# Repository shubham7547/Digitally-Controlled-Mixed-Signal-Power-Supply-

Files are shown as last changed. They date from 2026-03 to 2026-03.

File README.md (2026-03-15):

# Digitally Controlled Mixed-Signal Power Supply


[]()
[]()

[]()

A high-performance, digitally controlled benchtop power supply that bridges digital precision with an ultra-fast analog regulation loop. The system delivers an adjustable **0 to 30.0 V** output at up to **1.0 A**, featuring dual rotary quadrature encoders with digit-level selection, high-resolution readbacks on a 2.8" color TFT display, and a non-blocking embedded firmware architecture.

Developed at the **Centre for Electronic Design and Technology (CEDT)**, **Netaji Subhas University of Technology (NSUT), New Delhi**.

---

## Table of Contents

- [Architectural Philosophy](#architectural-philosophy)
- [System Architecture](#system-architecture)
- [Key Specifications](#key-specifications)
- [Hardware & Circuit Design](#hardware--circuit-design)
  - [1. AC Input & Bulk Rectification](#1-ac-input--bulk-rectification)
  - [2. Dual Auxiliary Buck Regulators](#2-dual-auxiliary-buck-regulators)
  - [3. Digital Setpoint Generation](#3-digital-setpoint-generation)
  - [4. Analog Voltage Regulation Loop](#4-analog-voltage-regulation-loop)
  - [5. Current Sensing & Differential Amplification](#5-current-sensing--differential-amplification)
- [Pin Assignment Table](#pin-assignment-table)
- [Firmware Architecture](#firmware-architecture)
  - [Interrupt-Driven Quadrature Decoding](#interrupt-driven-quadrature-decoding)
  - [Non-Blocking Scheduling](#non-blocking-scheduling)
  - [Software Current Limit Foldback](#software-current-limit-foldback)
- [Repository Structure](#repository-structure)
- [Getting Started](#getting-started)
  - [Required Libraries](#required-libraries)
  - [Hardware Setup & Flashing](#hardware-setup--flashing)
- [Author & Affiliation](#author--affiliation)
- [License](#license)

---

## Architectural Philosophy

Simpler DIY microcontroller-based power supplies often place the digital microcontroller inside the primary feedback loop or use PWM/software loops to regulate output voltage, leading to slow transient response, ADC latency, and stability issues.

This design enforces a strict separation of concerns:
1. **Digital Setpoint Domain:** The **Arduino Nano** and **TLC5618A 12-bit DAC** determine what target voltage/current limit is desired. They never carry load current and never sit directly inside the fast closed loop.
2. **Analog Control Domain:** An **LM358 op-amp error amplifier** continuously compares the scaled output feedback against the DAC setpoint in real time, driving high-power series-pass transistors (**MJE2955T PNP**) instantaneously without digital latency.

---

## System Architecture

```mermaid
flowchart TD
    Mains["Mains 230V AC"] --> T1["Step-Down Transformer\n(Off-Board)"]
    T1 --> Bridge["Bridge Rectifier (1N4007)\n+ 2x 4700µF Series Caps (50V eff.)"]
    Bridge --> RawDC["Raw DC Bus (~36V Peak)"]

    RawDC --> VR6["LM2575 Buck 1\nStep-down to 5.29V"]
    VR6 --> MCU["Arduino Nano\n(5V Digital Rail)"]

    RawDC --> VR5["LM2575 Buck 2\nStep-down to 30.0V Rail"]
    VR5 --> OpAmp["LM358 Error Amplifier\n(Analog Rail)"]

    MCU -->|Hardware SPI| DAC["TLC5618A 12-Bit DAC\n(Vref Generation)"]
    DAC -->|Vref Setpoint| OpAmp

    RawDC --> PassTrans["MJE2955T Power Transistor\nSeries-Pass Output Stage"]
    OpAmp -->|Drive Base| PassTrans

    PassTrans --> Load["Output Terminal (0–30V, 0–1A)"]
    Load --> Shunt["Low-Side Current Shunt (0.3 Ω)"]

    Load -->|Voltage Divider (R4/R5)| MCU_ADC_V["ADC Pin A1 (V_sense)"]
    Load -->|Voltage Divider| OpAmp
    Shunt -->|Diff-Amp (LM358)| MCU_ADC_I["ADC Pin A0 (I_sense)"]

    MCU -->|Hardware SPI| TFT["ILI9341 320x240 Color TFT\nSet V/I, Out V/I, CV/CC"]
    Encoders["Dual Rotary Encoders\n+ Push Switches"] -->|Interrupts D2, D6| MCU
```

---

## Key Specifications

| Parameter | Specification | Notes |
| :--- | :--- | :--- |
| **Output Voltage Range** | $0.000\text{ V}$ to $30.000\text{ V}$ | Continuously adjustable |
| **Output Current Range** | $0.000\text{ A}$ to $1.000\text{ A}$ | Software-limited foldback |
| **Microcontroller** | Arduino Nano | ATmega328P @ 16 MHz |
| **DAC Resolution** | 12-bit ($4096\text{ steps}$) | TLC5618A Dual SPI DAC |
| **DAC Reference Voltage** | $1.090\text{ V}$ | Shared with internal ADC reference |
| **Voltage Control Gain** | $22.886\text{ V/V}$ | $V_{\text{out}} / V_{\text{dac}}$ |
| **Raw DC Bus Voltage** | $\approx 36\text{ V peak}$ | Rectified AC secondary |
| **Digital Auxiliary Rail** | $5.29\text{ V}$ | Regulated via LM2575-ADJ (VR6) |
| **Analog Auxiliary Rail** | $30.02\text{ V}$ | Regulated via LM2575-ADJ (VR5) |
| **Current Sense Shunt** | $0.3\ \Omega$ | Low-side shunt resistor |
| **Current Sense Gain** | $0.7398\text{ V/A}$ | $0.216 \times 3.425$ diff-amp gain |
| **Display** | 2.8" ILI9341 Color TFT | $320 \times 240$ resolution via SPI |
| **Voltage Digit Steps** | $1\text{ mV},\ 10\text{ mV},\ 100\text{ mV},\ 1\text{ V},\ 10\text{ V}$ | 5 selectable cursor positions |
| **Current Digit Steps** | $1\text{ mA},\ 10\text{ mA},\ 100\text{ mA},\ 1\text{ A}$ | 4 selectable cursor positions |

---

## Hardware & Circuit Design

### 1. AC Input & Bulk Rectification
* Off-board mains transformer secondary connects via a 2-pin heavy-duty terminal block.
* Rectification via a full-wave 1N4007 diode bridge produces a $\approx 36\text{ V}$ peak raw DC bus.
* Bulk filtering uses **two $4700\ \mu\text{F},\ 25\text{ V}$ electrolytic capacitors in series** ($C_2, C_4$) to double the effective breakdown voltage rating to $50\text{ V}$, well above the $36\text{ V}$ peak headroom.

### 2. Dual Auxiliary Buck Regulators
To supply both digital control logic and high-voltage analog regulation without wasting excessive power through linear dropouts, two independent LM2575 switching buck converters are employed:
* **VR6 (Digital 5.29V Rail):** $R_2 = 3.3\text{ k}\Omega,\ R_1 = 1\text{ k}\Omega \implies V_{\text{out}} = 1.23 \times (1 + 3300/1000) = 5.29\text{ V}$. Powers the Arduino 5V net and logic.
* **VR5 (Analog 30.0V Rail):** $R_2 = 110\text{ k}\Omega,\ R_1 = 4.7\text{ k}\Omega \implies V_{\text{out}} = 1.23 \times (1 + 110000/4700) = 30.02\text{ V}$. Powers the LM358 op-amp error amplifier stage.

### 3. Digital Setpoint Generation
* Uses a **TLC5618A** 12-bit dual-channel DAC over hardware SPI.
* Output Channel A generates the analog reference voltage $V_{\text{ref}}$, filtered by capacitor $C_1$.
* Calculated DAC code:
  $$\text{Code} = \left(\frac{V_{\text{target}} / 22.886}{2 \times 1.090}\right) \times 4096$$

### 4. Analog Voltage Regulation Loop
* Implemented with an **LM358** operational amplifier configured as a fast error amplifier:
  - Non-inverting input ($+$): $V_{\text{ref}}$ from the TLC5618A DAC.
  - Inverting input ($-$): $V_{\text{sense}}$ from the output voltage divider.
* Op-amp output directly drives the base of the series-pass power transistor (**MJE2955T PNP**). Any instantaneous load variation is corrected within microseconds by the analog loop without waiting for microcontroller polling.

### 5. Current Sensing & Differential Amplification
* Output current flows through a precision $0.3\ \Omega$ low-side shunt ($R_3$).
* The differential voltage is amplified by the second half of the LM358 package ($0.7398\text{ V/A}$) and routed directly to ADC channel `A0` for continuous readback and software foldback protection.

---

## Pin Assignment Table

| Arduino Nano Pin | Signal Name | Connected To | Function / Description |
| :--- | :--- | :--- | :--- |
| **D2** | `ENC_V_A` | Voltage Encoder Phase A | Hardware interrupt, quadrature phase A |
| **D3** | `ENC_V_B` | Voltage Encoder Phase B | Quadrature phase B input |
| **D4** | `ENC_V_SW` | Voltage Encoder Push Switch | Switch to cycle active voltage edit digit |
| **D5** | `ENC_I_SW` | Current Encoder Push Switch | Switch to cycle active current limit digit |
| **D6** | `ENC_I_A` | Current Encoder Phase A | Hardware interrupt, quadrature phase A |
| **D7** | `ENC_I_B` | Current Encoder Phase B | Quadrature phase B input |
| **D8** | `TFT_CD` | ILI9341 D/C Pin | Display Data / Command selection |
| **D9** | `TFT_CS` | ILI9341 CS Pin | Display Chip Select |
| **D10** | `DAC_CS` | TLC5618A ~CS Pin | DAC Chip Select |
| **D11** | `MOSI` | Shared SPI Bus | Hardware SPI Data Out (TFT + DAC) |
| **D12** | `MISO` | Shared SPI Bus | Hardware SPI Data In (unused) |
| **D13** | `SCK` | Shared SPI Bus | Hardware SPI Clock (TFT + DAC) |
| **A0** | `ADC_ISENSE` | Current-Sense Diff-Amp Out | Analog input, output current readback |
| **A1** | `ADC_VSENSE` | Output Voltage Divider Out | Analog input, output voltage readback |
| **AREF** | `Vref` | Shared Reference Net | Common 1.090V DAC reference / ADC ref |

---

## Firmware Architecture

The firmware (`adj_power_combined.ino`) implements a fully non-blocking architecture without any `delay()` calls:

### Interrupt-Driven Quadrature Decoding
* Both rotary encoders trigger pin-change interrupts on their Phase A signals (`D2` and `D6`).
* A 2-bit quadrature Gray-code state machine evaluates transition validity to reject switch bounce and deliver crisp rotation response.

### Non-Blocking Scheduling
* **Encoder & DAC update:** Handled immediately on knob turn or switch press ($200\text{ ms}$ debounce).
* **Sensor Acquisition Loop:** Runs on a dedicated $100\text{ ms}$ periodic cadence (`SENSE_INTERVAL_MS`).
* **TFT Refresh Loop:** Runs on a distinct $150\text{ ms}$ cadence (`DISPLAY_INTERVAL_MS`), rewriting only modified text fields to prevent screen flicker and bus contention.

### Software Current Limit Foldback
If the measured load current exceeds the user-configured current limit ($I_{\text{out}} > I_{\text{limit}}$):
1. The firmware flags `ccActive = true` and updates the UI status badge from **CV** (Green) to **CC** (Yellow).
2. The firmware automatically walks the DAC voltage setpoint downward in small incremental steps until load current falls back within bounds.
3. Once the overload is removed, the original voltage setpoint is automatically restored.

---

## Repository Structure

```
Benchtop-Power-Supply/
├── README.md                                    # Comprehensive project documentation
├── .gitignore                                   # KiCad temporary & backup ignore rules
├── Block Diagram/
│   └── block_diagram.png                        # High-level system architecture block diagram
├── Code Files/
│   └── adj_power_combined/
│       └── adj_power_combined.ino               # Non-blocking firmware for Arduino Nano
├── Datasheet/
│   ├── LM2575.PDF                               # Step-down switching regulator datasheet
│   ├── lm358.pdf                                # Dual operational amplifier datasheet
│   ├── MJE2955T.PDF                             # PNP silicon power transistor datasheet
│   └── TLC5618.PDF                              # Dual 12-bit digital-to-analog converter datasheet
├── Kicad Files/
│   └── Adj_power/
│       ├── Adj_power.kicad_sch                  # KiCad schematic design
│       ├── Adj_power.kicad_pcb                  # KiCad printed circuit board layout
│       ├── Adj_power.kicad_pro                  # KiCad project file
│       ├── Adj_power.pdf                        # Printable schematic diagram PDF
│       └── bom/
│           └── ibom.html                        # Interactive HTML Bill of Materials
├── Report/
│   └── pwr_supply.pdf                           # Full technical engineering report document
└── Report Source File/
    └── pwr_supply/
        ├── adj_power_combined.ino               # Firmware source copy
        ├── block_diagram.png                    # Block diagram graphic
        ├── cedtnew.png                          # Institutional logo
        └── schematic.jpg                        # Circuit schematic render
```

---

## Getting Started

### Required Libraries
Install the following libraries via the Arduino Library Manager or place them in your `libraries/` directory:
- **SPI** (Standard Arduino SPI library)
- **LCDWIKI_GUI** (Graphical primitives)
- **LCDWIKI_SPI** (Hardware SPI driver for ILI9341)

### Hardware Setup & Flashing
1. Connect your **Arduino Nano** to your PC via USB.
2. Open `Code Files/adj_power_combined/adj_power_combined.ino` in Arduino IDE.
3. Configure your IDE settings under **Tools**:
   - **Board:** Arduino Nano
   - **Processor:** ATmega328P (or *ATmega328P (Old Bootloader)*)
   - **Port:** Select the corresponding COM port.
4. Verify and **Upload** the firmware sketch.
5. The ILI9341 display will illuminate and render the default UI with $0.000\text{ V}$ setpoint and $1.000\text{ A}$ current limit in **CV** mode.

---

## Author & Affiliation

* **Shubham Kumar**

**Centre for Electronic Design and Technology (CEDT)**  
**Netaji Subhas University of Technology (NSUT), New Delhi**  
*Project Date: March 2026*

---

## License

This project is open-source hardware and software available under the [MIT License](LICENSE).

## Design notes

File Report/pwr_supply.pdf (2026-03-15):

Centre for | Electronic Design | and Technology

### Netaji Subhas University of Technology , New Delhi

# Digitally Controlled Mixed-Signal Power Supply

### Submitted by

### Shubham Kumar

### Date: March 2026

# Contents

1. Synopsis | 4
2. Introduction | 5
3. System Overview | 6
4. Circuit Design & Working Principle | 9
5. Quantitative Design Analysis | 12
6. Firmware / Program Logic | 14

7. User Interface & Operation | 16
8. Bill of Materials | 17
9. Result | 19
10. Appendix | 20

# 1. Synopsis

This report documents the design of an adjustable linear bench power supply built around an Arduino Nano Every, a TLC5618A dual-channel DAC, and a 320×240 ILI9341 SPI TFT display. The supply uses a hybrid digital/analog control architecture: the user sets a target voltage and current limit via two rotary encoders, the Arduino converts that target into an analog reference voltage through the DAC, and a dedicated analog op-amp control loop regulates the actual output using series-pass transistors — the microcontroller never sits directly inside the high-current regulation path.

The design integrates rectification and bulk filtering, dual isolated buck-regulated auxiliary rails for clean control-electronics power, a compensated analog voltage control loop, a differential-amplifier current sense stage, and a digit-addressable rotary-encoder user interface with live TFT readout of set and measured voltage/current.

# 2. Introduction

Bench power supplies are a foundational tool for hardware development and debugging, and building one from discrete parts is a practical way to work through analog regulation, feedback control, mixed-signal interfacing, and embedded firmware design in a single project.

This design deliberately separates two concerns that are often conflated in simpler DIY supplies:

- Digital setpoint generation — the Arduino and DAC only decide what voltage/current is wanted; they never carry the load current or sit inside the fast feedback path.
- Analog regulation — a dedicated op-amp control loop, compensated for stability, does the actual real-time work of holding the output at the requested value, using series-pass transistors.

This separation means a firmware bug, a slow SPI transaction, or a display refresh can never destabilize the actual output regulation — a property worth having in any tool you plan to trust your other projects to.

# 3. System Overview

## 3.1 Block Diagram

Figure 1 shows the overall signal flow: mains AC is rectified into a high-current DC bus, two buck converters derive clean low-voltage rails for the digital and analog control electronics, the Arduino/DAC pair generates the setpoint, and the analog error amplifier closes the loop around the series-pass output stage. Current is sensed independently via a shunt and differential amplifier, and both voltage and current readings are displayed on the TFT.

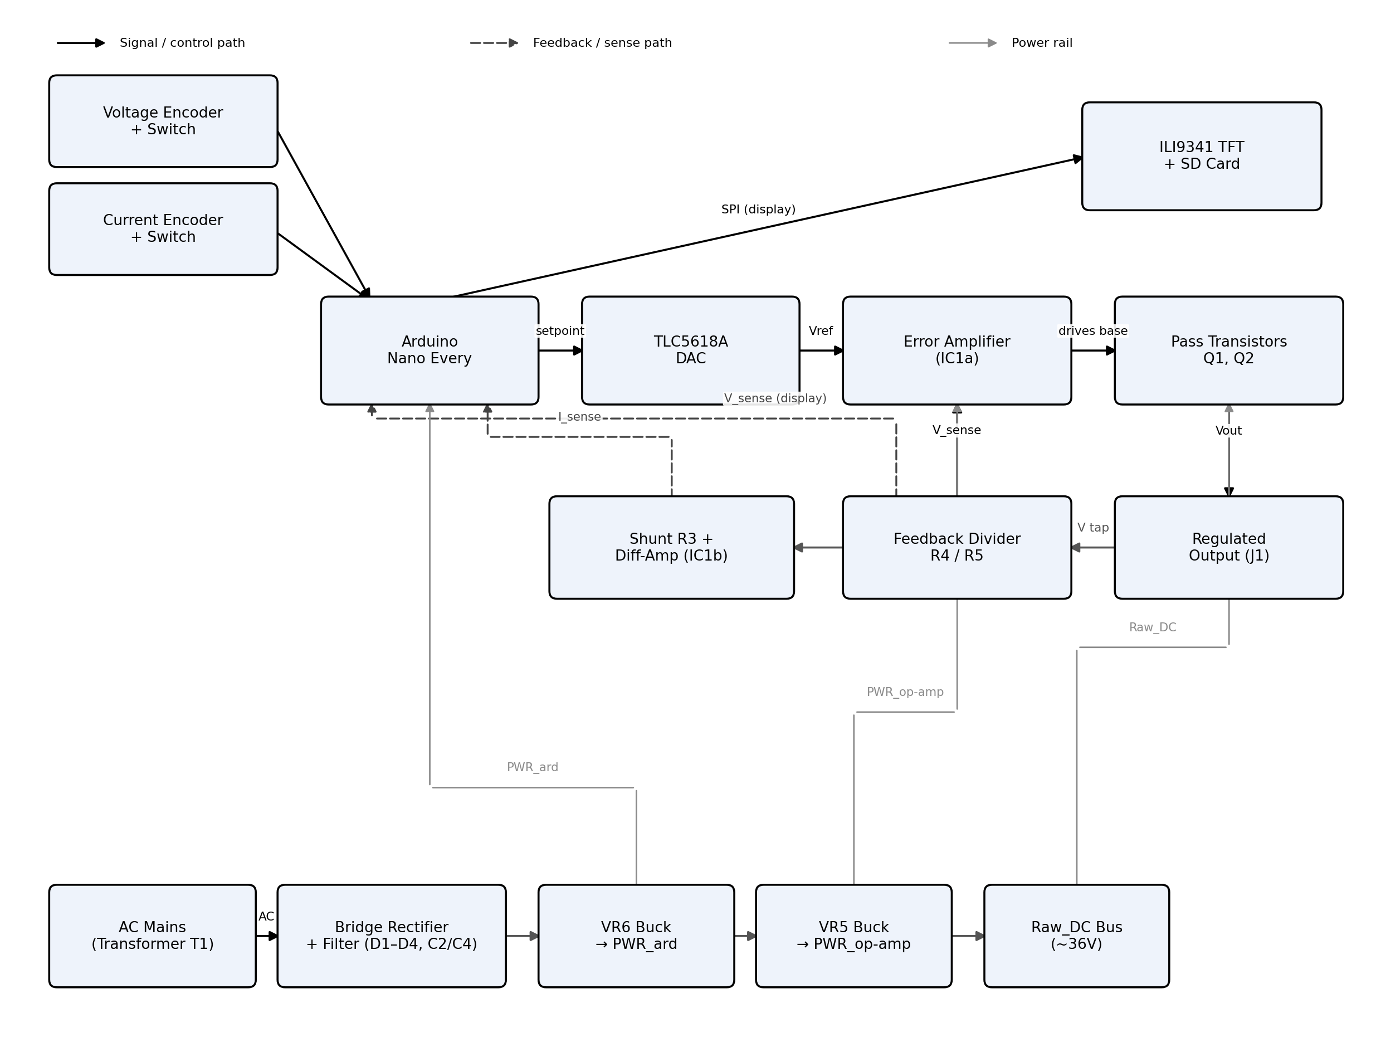
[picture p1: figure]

Figure 1: System block diagram.

## 3.2 Schematic Diagram

Figure 2 reproduces the full circuit schematic as designed in the PCB CAD tool, covering the AC input, dual buck auxiliary rails, DAC and Arduino interfacing, analog control loop, current-sense amplifier, and output stage.

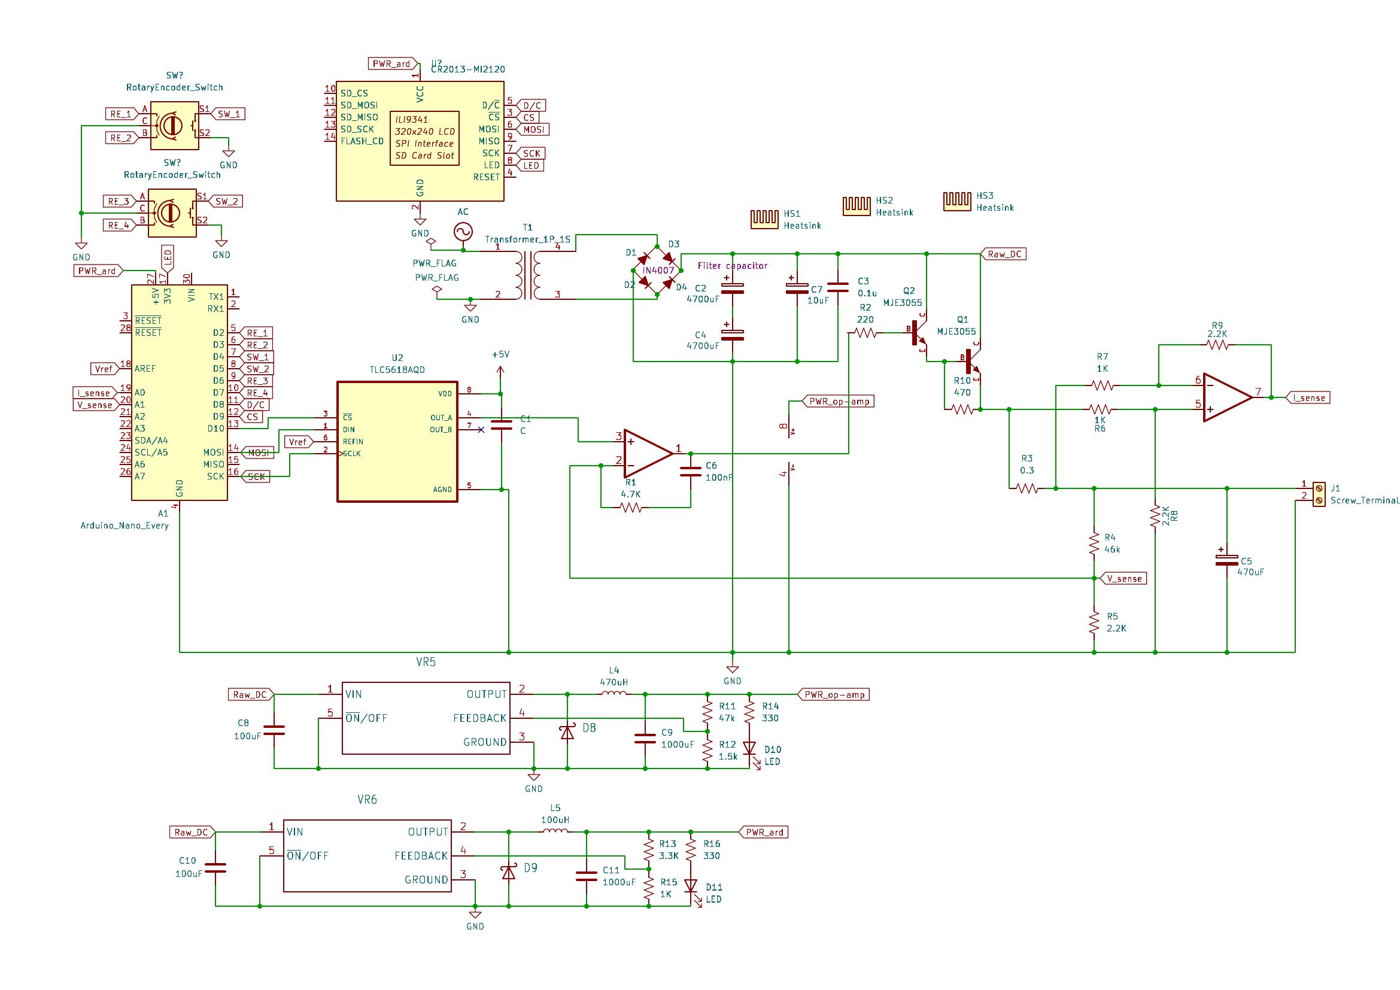
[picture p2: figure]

Figure 2: Full circuit schematic.

## 3.3 Pin Assignment Table

Table 1 summarizes the Arduino Nano Every pin assignments used in this design, confirmed against the schematic.

Pin | Signal | Connected To | Function
D2 | RE 1 | Voltage encoder A | Interrupt input, quadrature
| | | phase A
D3 | RE 2 | Voltage encoder B | Quadrature phase B
D4 | SW 1 | Voltage encoder switch | Selects digit place being edited
D5 | SW 2 | Current encoder switch | Selects digit place being edited
D6 | RE 3 | Current encoder A | Interrupt input, quadrature
| | | phase A
D7 | RE 4 | Current encoder B | Quadrature phase B
D8 | D/C | ILI9341 TFT | Data/Command select

Pin | Signal | Connected To | Function
D9 | CS | ILI9341 TFT | Chip select
D10 | CS (DAC) | TLC5618A DAC | Chip select
D11 | MOSI (hw SPI) | DAC + TFT (shared
bus)

SPI data out

D12 | MISO (hw SPI) | DAC + TFT (shared
bus)

SPI data in (unused by both)

D13 | SCK (hw SPI) | DAC + TFT (shared
bus)

SPI clock

A0 | I sense | Current-sense diff-amp
output

Analog input, output current readback
A1 | V sense | Voltage | feedback | di-
vider (R4/R5)

Analog input, output voltage readback
AREF | Vref | Shared DAC REFIN /
internal ADC ref

1.090 V reference, shared by DAC and ADC
5V | VCC | All digital peripherals | Supply voltage (PWR ard)
GND | GND | Entire circuit | Common ground

Table 1: Arduino Nano Every pin assignment.

Note: the two rotary encoder modules and the ILI9341 TFT/SD card module are off-board panel components, wired in via headers rather than populated as footprints on the main PCB — confirmed against the interactive BOM, which lists no footprints for these parts.

# 4. Circuit Design & Working Principle

## 4.1 AC Input and Rectification

An off-board mains transformer (T1) connects to the board via a 2-pin screw terminal footprint. Its secondary AC feeds a full-wave bridge rectifier (D1–D4, 1N4007), producing a pulsating DC bus of approximately 36 V peak.

Bulk smoothing is provided by C2 and C4 (4700 µF, 25 V each), deliberately wired in series. Since the rectifier output (∼36 V) exceeds a single capacitor’s 25 V rating, the series connection doubles the effective voltage rating to 50 V, at the cost of halving the effective capacitance to approximately 2350 µF. This produces the unregulated Raw DC rail that feeds everything downstream.

## 4.2 Auxiliary Regulated Rails

Two independent LM2575-class buck regulators step Raw DC down to two separate, clean low-voltage rails — physically isolating the digital control electronics’ switching noise from the sensitive analog control loop:

- VR5 → PWR op-amp — powers the dual op-amp (IC1). Feedback set by R11/R12, with L4 as the buck inductor, D8 as the freewheeling diode, and C8/C9 as input/output filtering.
- VR6 → PWR ard — powers the Arduino Nano Every. Feedback set by R13/R15, with L5 as the buck inductor, D9 as the freewheeling diode, and C10/C11 as input/output filtering.

Each rail has its own power-good indicator LED (D10 with R14 for VR5; D11 with R16 for VR6).

## 4.3 Digital Setpoint Generation

The Arduino Nano Every reads the two rotary encoders (with integrated push switches) and computes a target voltage and current limit. These setpoints are sent over SPI to the TLC5618A dual-channel DAC (U2); channel A’s output (OUT A), filtered by C1, becomes the analog reference voltage Vref that the control loop regulates toward. Channel B (OUT B) is left unconnected in the current design, reserved for future use.

## 4.4 Analog Voltage Control Loop

The actual voltage regulation is performed entirely in analog hardware by one half of the dual op-amp package (IC1), configured as an error amplifier:

- Non-inverting input (+): Vref, from the DAC.
- Inverting input (−): V sense, from the R4/R5 output feedback divider.
- Feedback network: R1 (4.7 kΩ) in series with C6 (0.1 µF), forming a Type II compensator.
- Output: drives the base of the parallel series-pass transistors, Q1 and Q2 (MJE3055), both mounted on a shared heatsink (HS1).

The Type II compensator is essential for loop stability: C6 alone would act as a pure integrator (a pole at the origin), giving very high DC gain for accurate regulation but pushing phase toward −90◦ across the whole spectrum. R1 in series with C6 introduces a compensating zero, restoring phase margin near the loop’s crossover frequency so the supply regulates accurately without oscillating.

Base-region resistors R2 (220 Ω) and R10 (470 Ω) bias the pass transistors; R10 additionally provides a fast discharge path for stored base charge, ensuring clean transistor turn-off and bleeding thermal leakage current that could otherwise cause voltage drift.

## 4.5 Current Sensing

Output current is measured independently of the voltage control loop, using the other half of the same dual op-amp package (IC1) as a classic four-resistor differential amplifier around a 0.3 Ω shunt resistor (R3):

- R6 (1 kΩ) and R7 (1 kΩ): matched input resistors from either side of the shunt.
- R8 (2.2 kΩ) and R9 (2.2 kΩ): matched feedback/reference resistors.
- Differential gain = R9/R7 = 2.2×, referenced to the output rail rather than system ground.

The amplified signal (I sense) is read directly by the Arduino’s ADC for display and any software-based current limiting; it does not feed into the hardware voltage loop, so there is currently no hardware constant-current (CC) mode — only a software-implemented foldback approach, described in Section 6.4.

## 4.6 Output Stage

A 470 µF output capacitor (C5) absorbs load transients, keeping the output stable during sudden current demand changes. The regulated output is delivered to the load through a 2-pin screw terminal (J1).

# 5. Quantitative Design Analysis

This section works through the actual voltage and current relationships at each stage, using the calibration constants confirmed in the firmware (DAC VREF = ADC VREF = 1.090 V, shared via a common reference net; V OUT GAIN = 22.886; I SENSE GAIN = 0.7398 V/A).

## 5.1 DAC Output Range

Vdac = 2 × DAC VREF ×

code
4096

(1)

At full-scale (code = 4095): Vdac,max = 2 × 1.090 × (4095/4096) ≈ 2.179 V. This is the maximum Vref the control loop can be asked to track.

## 5.2 Voltage Feedback Divider

Vsense = Vout ×

R5
R4 + R5

= Vout ×

2.2
48.2
≈ Vout × 0.04564 | (2)

Since the op-amp forces Vsense = Vref at DC equilibrium, Vout = Vref /0.04564 ≈ Vref ×
21.91. This resistor-derived gain (21.91×) closely matches the firmware’s independently calibrated V OUT GAIN (22.886×), a good cross-check that the divider values are doing what the design intends.

Combining the two: the DAC’s full-scale output could theoretically command up to ∼49.9 V, but this is never reached in practice — the firmware clamps the setpoint to 30 V, and Raw DC itself (∼36 V) limits the realistic ceiling to a few volts below that, accounting for pass-transistor dropout.

## 5.3 Buck Regulator Output Voltages

Per the regulator’s datasheet, the adjustable buck output follows:

Vout = Vref ×

(︃
1 +

R2
R1

)︃
, | Vref = 1.23 V | (3)

where R2 is the resistor from FEEDBACK to Vout, and R1 is the resistor from FEED-BACK to GND. For VR6 (R13 = 3.3 kΩ as R2, R15 = 1 kΩ as R1): Vout = 1.23 × (1 + 3300/1000) = 5.29 V — a clean, sensible value for directly powering the Arduino’s 5 V pin.

For VR5, R2 = 110kΩ and R1 = 4.7kΩ give Vout = 1.23 × (1 + 110000/4700) ≈ 30.02V — confirming the corrected feedback network achieves the intended 30V rail well within Raw DC’s 36V headroom.

## 5.4 Current-Sense Path

Vshunt = Iout × R3 = Iout × 0.3; Isense,ideal = Vshunt ×

R9
R7

= Iout × 0.66 V/A (4)

The resistor-predicted gain (0.66 V/A) is reasonably close to the firmware’s empirically calibrated I SENSE GAIN (0.7398 V/A); the firmware’s measured value should be treated as authoritative for real current calculations, since it accounts for real-world component tolerances that the ideal resistor math does not.

## 5.5 ADC Readback

Because the firmware calls analogReference(INTERNAL), the ADC’s full-scale reference is 1.090 V (the same physical reference feeding the DAC’s REFIN), not the board’s 5 V supply rail. A raw 10-bit ADC code therefore converts as:

Vout,measured =

(︃
rawADC
1023

× 1.090)︃
× 22.886 | (5)

Iout,measured =

(︃
rawADC
1023

× 1.090)︃
/0.7398 | (6)

# 6. Firmware / Program Logic

The firmware runs a fully non-blocking main loop — no delay() calls — so encoder input remains responsive while sensor reads and display updates happen on their own periodic schedules.

## 6.1 Encoder Input Handling

Both rotary encoders are decoded via hardware interrupts on their A-phase pins, using a 2-bit quadrature state-transition check to register clean up/down steps and reject contact bounce. Each encoder’s push switch cycles a “digit cursor” (thousandths → hundredths → tenths → ones → tens), and turning the knob adjusts the setpoint by that digit’s place value — letting the same control provide both fine and coarse adjustment.

## 6.2 DAC Control

The DAC is driven over hardware SPI using the confirmed 16-bit control-word format: the top nibble selects DAC A or DAC B and sets fast/normal power mode (0xC000 for DAC A, 0x4000 for DAC B), and the remaining 12 bits carry the output code. A dedicated voltageToCode() function inverts the DAC transfer function to compute the code needed for a requested output voltage.

## 6.3 Display Rendering

The TFT is driven via the LCDWIKI SPI library over the same hardware SPI bus as the DAC, each with its own independent chip-select line (D9 for the TFT, D10 for the DAC) confirmed against the schematic and the physical board. The display shows Set V, Out V, Set I, and Out I, with a small cursor bar indicating which digit each encoder is currently editing, and a CV/CC status indicator.

## 6.4 Software Current Limiting

Since no hardware current-control loop exists on this board, the firmware implements a software foldback: if measured current exceeds the set limit, the firmware walks the DAC’s voltage command down in small steps until current settles back within the limit, restoring the original setpoint once the overcurrent condition clears. This is deliberately conservative — it protects against sustained overcurrent but is far slower than a true analog CC loop and should not be relied upon for short-circuit protection.

# 7. User Interface & Operation

## 7.1 Voltage / Current Setpoint Adjustment

Two rotary encoders — one for voltage, one for current limit — let the user dial in a target value digit-by-digit, with the associated push switch selecting which digit is currently being edited.

## 7.2 Display Readout

The TFT continuously shows both the requested (Set) and actual (Out) voltage and current, refreshed on a fixed interval independent of encoder input, so the display never becomes a bottleneck for control responsiveness.

## 7.3 CV/CC Indication

A status indicator on the display shows CV (constant voltage) during normal operation, switching to CC (constant current) whenever the software current-limit foldback described in Section 6.4 is actively reducing the output to respect the current limit.

# 8. Bill of Materials

Table 2 lists every component used in the design, cross-referenced against the project’s interactive BOM export and the schematic.

# | Component | Reference(s) Specification | Qty

1 | Transformer | T1 | Transformer 1P 1S | (off-
board)

1

2 | Bridge | rectifier
diodes

D1, D2, D3,
D4
1N4007 | 4
3 | Bulk filter capaci-
tors
C2, C4 | 4700 µF, | 25 V | (series-
connected)

2

4 | Buck regulator IC | VR5, VR6 | LM2575-class adjustable
buck

2

5 | Buck inductors | L4, L5 | 470 µH, 100 µH | 2
6 | Buck flyback diodes D8, D9 | Generic diode (DO-41) | 2
7 | Buck filter capaci-
tors

C8, C9, C10,
C11
100 µF / 1000 µF | 4
8 | Buck feedback resis-
tors

R11, R12,
R13, R15
110KΩ 4.7KΩ | 4
9 | Status LEDs | D10, D11 | 5 mm LED | 2
10 | LED series resistors R14, R16 | 330 Ω | 2
11 | Dual op-amp | IC1 | 8-pin DIP dual op-amp | 1
12 | Voltage feedback di-
vider
R4, R5 | 46 kΩ, 2.2 kΩ | 2
13 | Loop compensation | R1, C6 | 4.7 kΩ, 0.1 µF | 2
14 | Series-pass transis-
tors
Q1, Q2 | MJE3055 (NPN, TO-220) 2
15 | Base resistors | R2, R10 | 220 Ω, 470 Ω | 2
16 | Heatsinks | HS1, | HS2,
HS3

TO-220 / TO-247 class
heatsink

3

17 | Current shunt | R3 | 0.3 Ω | 1
18 | Diff-amp resistors | R6, R7, R8,
R9
1 kΩ, 1 kΩ, 2.2 kΩ, 2.2 kΩ | 4
19 | Output capacitor | C5 | 470 µF | 1
20 | Output terminal | J1 | 2-pin screw terminal | 1
21 | DAC output filter | C1 | Ceramic disc capacitor | 1
22 | DAC breakout | U2 | TLC5618AQD (dual 12-
bit DAC)

1

# | Component | Reference(s) Specification | Qty

23 | Microcontroller | A1 | Arduino Nano Every | 1
24 | Rotary encoders w/
| switch
— (off-board) | Mechanical | quadrature
| | | encoder | 2
25 | TFT display mod-
| ule | — (off-board) | ILI9341 320×240 SPI +
| | | SD card slot | 1

Table 2: Bill of Materials.

# 9. Result

The design has been validated stage-by-stage against the schematic and BOM: the voltage control loop’s resistor-derived gain matches the firmware’s calibrated gain within ∼4%, and the current-sense path’s resistor-derived gain matches within ∼12% (with the firmware’s empirically measured value treated as authoritative).

Firmware for TFT bring-up, combined encoder/DAC/display operation, and the underlying SPI/DAC control-word derivation were each independently developed and are included in the project’s code appendix.

# 10. Appendix

## 10.1 Code Files

- adj power combined.ino — full combined firmware (encoders, DAC, TFT, software current-limit foldback)
- tft bringup.ino — standalone TFT bring-up / display test sketch

## 10.2 References

- TLC5618A dual 12-bit DAC datasheet
- LM2575-family adjustable buck regulator datasheet (output voltage design equation)
- Arduino Nano Every reference documentation
- ILI9341 TFT controller datasheet

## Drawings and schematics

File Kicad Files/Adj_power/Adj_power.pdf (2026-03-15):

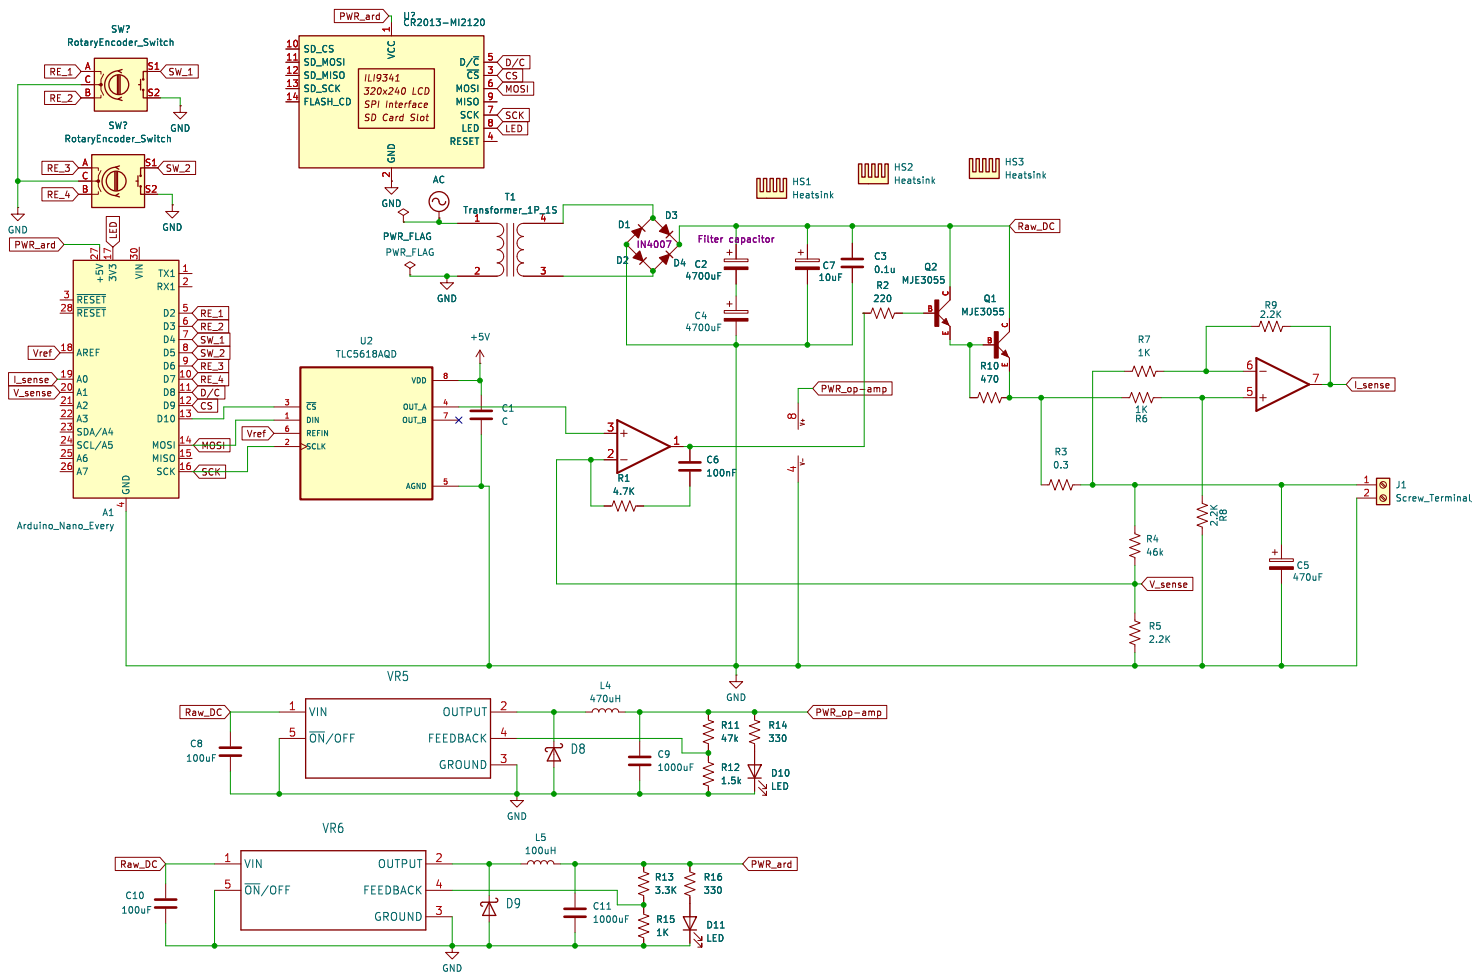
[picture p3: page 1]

2 D/~{C}5 ~{CS}3 MOSI 6 MISO 9 SCK 7

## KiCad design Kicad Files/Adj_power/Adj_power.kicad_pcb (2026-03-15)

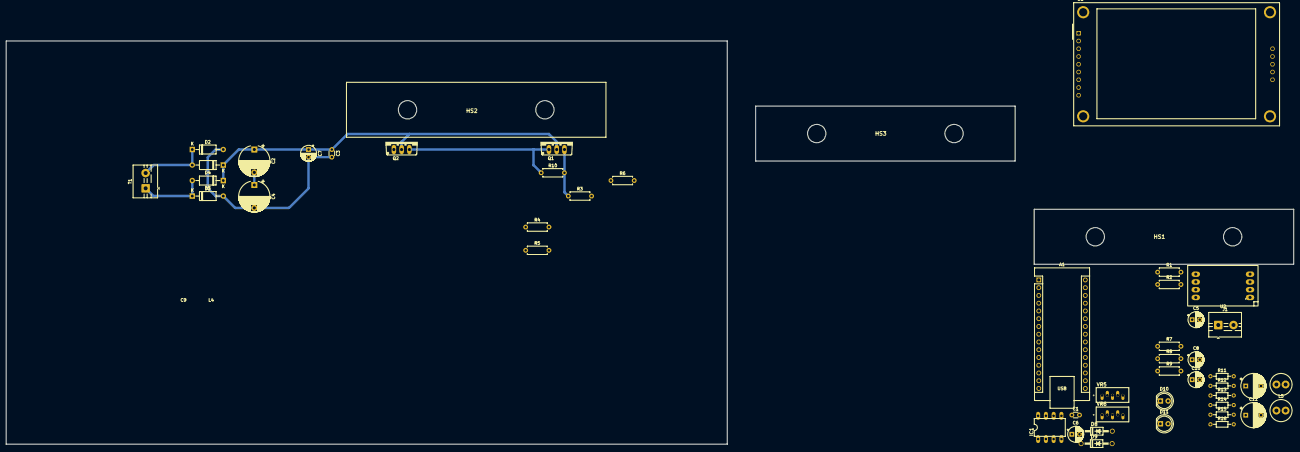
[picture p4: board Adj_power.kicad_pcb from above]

Board: 2 copper layers, 421.8 x 132.1 mm, 50 parts (0 on the bottom side), 32 nets.

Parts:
A1: Arduino_Nano_Every; Arduino_Nano
C1: C; C_Disc_D3.0mm_W1.6mm_P2.50mm
C2, C4: 4700uF; CP_Radial_D10.0mm_P7.50mm
C3: 0.1u; C_Disc_D3.0mm_W1.6mm_P2.50mm
C5: 470uF; CP_Radial_D5.0mm_P2.50mm
C6: 100nF; CP_Radial_D5.0mm_P2.50mm
C7: 10uF; CP_Radial_D5.0mm_P2.50mm
C8, C10: 100uF; CP_Radial_D5.0mm_P2.50mm
C9, C11: 1000uF; CP_Radial_D8.0mm_P5.00mm
D1, D2, D3, D4: D_45deg_Filled; D_A-405_P10.16mm_Horizontal
D8, D9: DO41-10
D10, D11: LED; LED_D5.0mm
HS1, HS2, HS3: Heatsink; HEATSINK
IC1: DIL08
J1: Screw_Terminal_01x02; TerminalBlock_MaiXu_MX126-5.0-02P_1x02_P5.00mm
L4: 470uH; L_Radial_D7.0mm_P3.00mm
L5: 100uH; L_Radial_D7.0mm_P3.00mm
Q1, Q2: MJE3055; TO220AV
R1: 4.7K; R_Axial_DIN0207_L6.3mm_D2.5mm_P7.62mm_Horizontal
R2: 220; R_Axial_DIN0207_L6.3mm_D2.5mm_P7.62mm_Horizontal
R3: 0.3; R_Axial_DIN0207_L6.3mm_D2.5mm_P7.62mm_Horizontal
R4: 46k; R_Axial_DIN0207_L6.3mm_D2.5mm_P7.62mm_Horizontal
R5, R8, R9: 2.2K; R_Axial_DIN0207_L6.3mm_D2.5mm_P7.62mm_Horizontal
R6, R7: 1K; R_Axial_DIN0207_L6.3mm_D2.5mm_P7.62mm_Horizontal
R10: 470; R_Axial_DIN0207_L6.3mm_D2.5mm_P7.62mm_Horizontal
R11: 47k; R_Axial_DIN0204_L3.6mm_D1.6mm_P7.62mm_Horizontal
R12: 1.5k; R_Axial_DIN0204_L3.6mm_D1.6mm_P7.62mm_Horizontal
R13: 3.3K; R_Axial_DIN0204_L3.6mm_D1.6mm_P7.62mm_Horizontal
R14, R16: 330; R_Axial_DIN0204_L3.6mm_D1.6mm_P7.62mm_Horizontal
R15: 1K; R_Axial_DIN0204_L3.6mm_D1.6mm_P7.62mm_Horizontal
T1: Transformer_1P_1S; TerminalBlock_MaiXu_MX126-5.0-02P_1x02_P5.00mm
U1: CR2013-MI2120
U2: TLC5618AQD; BOB
VR5, VR6: TO170P1067X483X1651-5

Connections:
+5V: C1.1, U2.8 (VDD)
D/C: A1.11 (D8), U1.5 (D/~C)
GND: A1.4 (GND), A1.29 (GND), C1.2, C3.2, C4.2, C5.2, C7.2, C8.1, C9.2, C10.1, C11.2, D1.2 (A), D2.2 (A), D8.A, D9.A, D10.1 (K), D11.1 (K), IC1.4 (V-), J1.2, R5.2, R8.1, R12.2, R15.2, T1.2 (AB), U1.2 (GND), U2.5 (AGND), VR5.3 (GROUND), VR5.5 (~ON/OFF), VR6.3 (GROUND), VR6.5 (~ON/OFF)
I_sense: A1.19 (A0), IC1.7 (OUT), R9.1
LED: A1.17 (3V3), U1.8 (LED)
MOSI: A1.14 (MOSI), U1.6 (MOSI), U2.1 (DIN)
unnamed: A1.13 (D10), U2.3 (~CS)
unnamed: C2.2, C4.1
unnamed: C6.2, R1.2
unnamed: D1.1 (K), D3.2 (A)
unnamed: D2.1 (K), D4.2 (A)
unnamed: D10.2 (A), R14.2
unnamed: D11.2 (A), R16.2
unnamed: IC1.3 (+IN), U2.4 (OUT_A)
unnamed: C6.1, IC1.1 (OUT), R2.1
unnamed: IC1.5 (+IN), R6.2, R8.2
unnamed: IC1.6 (-IN), R7.2, R9.2
unnamed: C5.1, J1.1, R3.2, R4.1, R7.1
unnamed: Q1.B, Q2.E, R10.1
unnamed: Q1.E, R3.1, R6.1, R10.2
unnamed: Q2.B, R2.2
unnamed: R11.2, R12.1, VR5.4 (FEEDBACK)
unnamed: D8.C, L4.1, VR5.2 (OUTPUT)
unnamed: R13.2, R15.1, VR6.4 (FEEDBACK)
unnamed: D9.C, L5.1, VR6.2 (OUTPUT)
PWR_ard: A1.27 (+5V), C11.1, L5.2, R13.1, R16.1, U1.1 (VCC)
PWR_op-amp: C9.1, IC1.8 (V+), L4.2, R11.1, R14.1
Raw_DC: C2.1, C3.1, C7.1, C8.2, C10.2, D3.1 (K), D4.1 (K), Q1.C, Q2.C, VR5.1 (VIN), VR6.1 (VIN)
SCK: A1.16 (SCK), U1.7 (SCK), U2.2 (SCLK)
TFT_CS: A1.12 (D9), U1.3 (~CS)
V_sense: A1.20 (A1), IC1.2 (-IN), R1.1, R4.2, R5.1
Vref: A1.18 (AREF), U2.6 (REFIN)

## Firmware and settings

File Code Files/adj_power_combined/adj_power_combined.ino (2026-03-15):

/* ============================================================================
   ADJUSTABLE BENCH POWER SUPPLY - Combined firmware
   ============================================================================
   - Two rotary encoders (+push switches) set a Voltage target and a Current
     limit target. Pressing a switch moves which digit that encoder edits.
   - Voltage setpoint -> DAC channel A -> Vref -> analog op-amp loop -> pass
     transistors. This is the real, hardware voltage regulation path.
   - Current limit has no dedicated analog loop on this board, so it's
     enforced here in software: if measured current exceeds the limit, the
     DAC's voltage command is walked down until current backs off (a soft
     foldback CC, not a substitute for a hardware loop).
   - TFT shows Set V / Out V, Set I-limit / Out I, and CV/CC status.

   PINS - confirmed against the schematic AND the real board:
     TFT   CS   -> D9      TFT   D/C  -> D8
     DAC   CS   -> D10     DAC   DIN  -> MOSI (D11, hw SPI)
     DAC   SCLK -> SCK (D13, hw SPI)  TFT/DAC MISO -> D12 (hw SPI, unused)
     TFT   LED  -> tied to 3V3 on the board (no Arduino pin)
     TFT   RESET-> floating on the board (no Arduino pin)
     Voltage encoder: RE_1=D2, RE_2=D3, SW_1=D4
     Current encoder: RE_3=D6, RE_4=D7, SW_2=D5
     I_sense -> A0     V_sense -> A1
   ============================================================================ */

#include <SPI.h>
#include <LCDWIKI_GUI.h>
#include <LCDWIKI_SPI.h>

// ---------------------------------------------------------------------------
// PIN MAP (confirmed)
// ---------------------------------------------------------------------------
#define MODEL     ILI9341

#define TFT_CS     9
#define TFT_CD     8            // D/C
#define TFT_MISO  12            // hw SPI, unused by TFT but constructor wants it
#define TFT_MOSI  11            // hw SPI
#define TFT_RST   -1            // floating on this board
#define TFT_SCK   13            // hw SPI
#define TFT_LED   -1            // tied to 3V3 on this board

#define DAC_CS    10            // TLC5618A ~CS

#define ENC_V_A    2            // RE_1 (interrupt-capable)
#define ENC_V_B    3            // RE_2
#define ENC_V_SW   4            // SW_1

#define ENC_I_A    6            // RE_3 (interrupt-capable)
#define ENC_I_B    7            // RE_4
#define ENC_I_SW   5            // SW_2

#define ADC_ISENSE A0           // I_sense
#define ADC_VSENSE A1           // V_sense

// ---------------------------------------------------------------------------
// CALIBRATION CONSTANTS
// ---------------------------------------------------------------------------
const float DAC_VREF     = 1.090;          // V, DAC's REFIN voltage (= Arduino's internal ADC ref, shared)
const float V_OUT_GAIN   = 22.886;         // op-amp/feedback gain: DAC volts -> PSU output volts
const float ADC_VREF     = 1.090;          // Arduino internal ADC reference (analogReference(INTERNAL))
const float I_SENSE_GAIN = 0.216 * 3.425;  // shunt + diff-amp: volts at ADC pin per amp of output current

const float V_MAX = 30.0;
const float I_MAX = 3.0;

// ---------------------------------------------------------------------------
// TFT OBJECT (hardware SPI - pins passed match the real hw SPI pins, so the
// library uses the SPI peripheral rather than bit-banging)
// ---------------------------------------------------------------------------
LCDWIKI_SPI mylcd(MODEL, TFT_CS, TFT_CD, TFT_MISO, TFT_MOSI, TFT_RST, TFT_SCK, TFT_LED);

#define COL_BG    0x0000  // black
#define COL_LABEL 0x7BEF  // grey
#define COL_SETV  0x07FF  // cyan
#define COL_OUTV  0xFFFF  // white
#define COL_CV    0x07E0  // green
#define COL_CC    0xFFE0  // yellow
#define COL_CURSOR 0xFD20 // orange

// ---------------------------------------------------------------------------
// GLOBAL STATE
// ---------------------------------------------------------------------------
const float vSteps[] = {0.001, 0.01, 0.1, 1.0, 10.0};
const uint8_t V_DIGIT_COUNT = 5;
const float iSteps[] = {0.001, 0.01, 0.1, 1.0};
const uint8_t I_DIGIT_COUNT = 4;

int vDigit = 2;
int iDigit = 2;

float setVoltage      = 0.0;
float setCurrentLimit = 1.0;
float measuredVoltage = 0.0;
float measuredCurrent = 0.0;

bool  ccActive = false;
float ccBackoffVoltage = -1;

volatile int8_t encVDelta = 0;
volatile uint8_t encVLastState = 0;
volatile int8_t encIDelta = 0;
volatile uint8_t encILastState = 0;

unsigned long lastVSwPress = 0, lastISwPress = 0;
const unsigned long SW_DEBOUNCE_MS = 200;

unsigned long lastSenseMs = 0;
const unsigned long SENSE_INTERVAL_MS = 100;
unsigned long lastDisplayMs = 0;
const unsigned long DISPLAY_INTERVAL_MS = 150;

float lastDrawnSetV = -1, lastDrawnMeasV = -1;
float lastDrawnSetI = -1, lastDrawnMeasI = -1;
int   lastDrawnVDigit = -1, lastDrawnIDigit = -1;
bool  lastDrawnCC = false;

// ---------------------------------------------------------------------------
// DAC (TLC5618A) SPI DRIVER - hardware SPI, shares the bus with the TFT
// ---------------------------------------------------------------------------
// 16-bit word = [R1 SPD PWR R0][12-bit code]
//   R1,R0 = 10 -> write + update DAC A -> top nibble 1100 = 0xC (SPD=1,PWR=0)
//   R1,R0 = 00 -> write + update DAC B -> top nibble 0100 = 0x4 (SPD=1,PWR=0)
void dacWrite(uint8_t channel, uint16_t code) {
  if (code > 4095) code = 4095;
  uint16_t command = (channel == 0 ? 0xC000 : 0x4000) | (code & 0x0FFF);

  SPI.beginTransaction(SPISettings(1000000, MSBFIRST, SPI_MODE2));
  digitalWrite(DAC_CS, LOW);
  SPI.transfer(command >> 8);
  SPI.transfer(command & 0xFF);
  digitalWrite(DAC_CS, HIGH);
  SPI.endTransaction();
}

uint16_t voltageToCode(float volts) {
  if (volts < 0) volts = 0;
  if (volts > V_MAX) volts = V_MAX;
  float dacVoltsNeeded = volts / V_OUT_GAIN;
  float code = (dacVoltsNeeded / (2.0 * DAC_VREF)) * 4096.0;
  if (code < 0) code = 0;
  if (code > 4095) code = 4095;
  return (uint16_t)(code + 0.5);
}

// ---------------------------------------------------------------------------
// ENCODER QUADRATURE DECODING (interrupt-driven)
// ---------------------------------------------------------------------------
void readEncoderV() {
  uint8_t state = (digitalRead(ENC_V_A) << 1) | digitalRead(ENC_V_B);
  if (state == encVLastState) return;
  if ((encVLastState == 0b00 && state == 0b01) ||
      (encVLastState == 0b01 && state == 0b11) ||
      (encVLastState == 0b11 && state == 0b10) ||
      (encVLastState == 0b10 && state == 0b00)) {
    encVDelta++;
  } else if ((encVLastState == 0b00 && state == 0b10) ||
             (encVLastState == 0b10 && state == 0b11) ||
             (encVLastState == 0b11 && state == 0b01) ||
             (encVLastState == 0b01 && state == 0b00)) {
    encVDelta--;
  }
  encVLastState = state;
}

void readEncoderI() {
  uint8_t state = (digitalRead(ENC_I_A) << 1) | digitalRead(ENC_I_B);
  if (state == encILastState) return;
  if ((encILastState == 0b00 && state == 0b01) ||
      (encILastState == 0b01 && state == 0b11) ||
      (encILastState == 0b11 && state == 0b10) ||
      (encILastState == 0b10 && state == 0b00)) {
    encIDelta++;
  } else if ((encILastState == 0b00 && state == 0b10) ||
             (encILastState == 0b10 && state == 0b11) ||
             (encILastState == 0b11 && state == 0b01) ||
             (encILastState == 0b01 && state == 0b00)) {
    encIDelta--;
  }
  encILastState = state;
}

// ---------------------------------------------------------------------------
// SETUP
// ---------------------------------------------------------------------------
void setup() {
  pinMode(DAC_CS, OUTPUT);
  digitalWrite(DAC_CS, HIGH);
  SPI.begin();

  analogReference(INTERNAL);
  pinMode(ADC_VSENSE, INPUT);
  pinMode(ADC_ISENSE, INPUT);

  pinMode(ENC_V_A, INPUT_PULLUP);
  pinMode(ENC_V_B, INPUT_PULLUP);
  pinMode(ENC_V_SW, INPUT_PULLUP);
  pinMode(ENC_I_A, INPUT_PULLUP);
  pinMode(ENC_I_B, INPUT_PULLUP);
  pinMode(ENC_I_SW, INPUT_PULLUP);

  attachInterrupt(digitalPinToInterrupt(ENC_V_A), readEncoderV, CHANGE);
  attachInterrupt(digitalPinToInterrupt(ENC_I_A), readEncoderI, CHANGE);

  mylcd.Init_LCD();
  mylcd.Set_Rotation(1);
  mylcd.Fill_Screen(COL_BG);
  drawStaticUI();

  dacWrite(0, voltageToCode(0));   // power up at 0V for safety
}

// ---------------------------------------------------------------------------
// MAIN LOOP (non-blocking)
// ---------------------------------------------------------------------------
void loop() {
  handleVoltageEncoder();
  handleCurrentEncoder();
  handleSwitches();

  if (millis() - lastSenseMs >= SENSE_INTERVAL_MS) {
    lastSenseMs = millis();
    readSensors();
    applySoftwareCurrentLimit();
  }

  if (millis() - lastDisplayMs >= DISPLAY_INTERVAL_MS) {
    lastDisplayMs = millis();
    updateDisplay();
  }
}

void handleVoltageEncoder() {
  noInterrupts();
  int8_t delta = encVDelta;
  encVDelta = 0;
  interrupts();
  if (delta == 0) return;

  setVoltage += delta * vSteps[vDigit];
  if (setVoltage < 0) setVoltage = 0;
  if (setVoltage > V_MAX) setVoltage = V_MAX;
  ccBackoffVoltage = -1;
  dacWrite(0, voltageToCode(setVoltage));
}

void handleCurrentEncoder() {
  noInterrupts();
  int8_t delta = encIDelta;
  encIDelta = 0;
  interrupts();
  if (delta == 0) return;

  setCurrentLimit += delta * iSteps[iDigit];
  if (setCurrentLimit < 0) setCurrentLimit = 0;
  if (setCurrentLimit > I_MAX) setCurrentLimit = I_MAX;
}

void handleSwitches() {
  if (digitalRead(ENC_V_SW) == LOW && millis() - lastVSwPress > SW_DEBOUNCE_MS) {
    lastVSwPress = millis();
    vDigit = (vDigit + 1) % V_DIGIT_COUNT;
  }
  if (digitalRead(ENC_I_SW) == LOW && millis() - lastISwPress > SW_DEBOUNCE_MS) {
    lastISwPress = millis();
    iDigit = (iDigit + 1) % I_DIGIT_COUNT;
  }
}

void readSensors() {
  int rawV = analogRead(ADC_VSENSE);
  int rawI = analogRead(ADC_ISENSE);
  measuredVoltage = (rawV * ADC_VREF * V_OUT_GAIN) / 1023.0;
  float senseVolts = (rawI * ADC_VREF) / 1023.0;
  measuredCurrent = senseVolts / I_SENSE_GAIN;
}

void applySoftwareCurrentLimit() {
  const float CC_STEP_V = 0.05;

  if (measuredCurrent > setCurrentLimit) {
    if (ccBackoffVoltage < 0) ccBackoffVoltage = setVoltage;
    ccBackoffVoltage -= CC_STEP_V;
    if (ccBackoffVoltage < 0) ccBackoffVoltage = 0;
    dacWrite(0, voltageToCode(ccBackoffVoltage));
    ccActive = true;
  } else if (ccActive) {
    ccActive = false;
    ccBackoffVoltage = -1;
    dacWrite(0, voltageToCode(setVoltage));
  }
}

// ---------------------------------------------------------------------------
// DISPLAY (LCDWIKI_GUI API: Fill_Rectangle/Draw_Rectangle take two corner
// points, not x/y/width/height)
// ---------------------------------------------------------------------------
// fixed pixel x-offsets of each digit within "TT.HHH" at text size 3 (18px/char)
// string layout: [0]T [1]T [2]. [3]H [4]H [5]H
const uint8_t vDigitCharPos[V_DIGIT_COUNT] = {5, 4, 3, 1, 0}; // idx0=thousandths..idx4=tens
// string layout for current "I.III": [0]I [1]. [2]I [3]I [4]I
const uint8_t iDigitCharPos[I_DIGIT_COUNT] = {4, 3, 2, 0};    // idx0=thousandths..idx3=ones

void drawStaticUI() {
  mylcd.Set_Text_Mode(0);
  mylcd.Set_Text_Back_colour(COL_BG);
  mylcd.Set_Text_colour(0xFFFF);
  mylcd.Set_Text_Size(2);
  mylcd.Print_String("BENCH POWER SUPPLY", 10, 8);

  mylcd.Set_Draw_color(COL_LABEL);
  mylcd.Draw_Line(0, 30, 320, 30);

  mylcd.Set_Text_colour(COL_LABEL);
  mylcd.Print_String("SET V", 10, 45);
  mylcd.Print_String("OUT V", 10, 100);
  mylcd.Print_String("SET I", 170, 45);
  mylcd.Print_String("OUT I", 170, 100);

  mylcd.Set_Draw_color(COL_LABEL);
  mylcd.Draw_Line(0, 150, 320, 150);
}

// Fixed-width zero-padded formatting (avoids sprintf's unreliable %f support
// on AVR/megaAVR cores - dtostrf is always available)
void formatFixed(char* buf, float value, uint8_t intDigits, uint8_t decDigits) {
  uint8_t width = intDigits + decDigits + 1;
  dtostrf(value, width, decDigits, buf);
  for (uint8_t i = 0; i < width; i++) {
    if (buf[i] == ' ') buf[i] = '0';
    else break;
  }
}

void drawField(int x, int y, float value, float &lastValue, uint16_t color,
               uint8_t intDigits, uint8_t decDigits, const char* unit) {
  if (fabs(value - lastValue) < 0.0005) return;
  lastValue = value;

  char buf[8];
  formatFixed(buf, value, intDigits, decDigits);

  mylcd.Set_Draw_color(COL_BG);
  mylcd.Fill_Rectangle(x, y, x + 150, y + 23);   // clear old text (two corner points)

  mylcd.Set_Text_Size(3);
  mylcd.Set_Text_colour(color);
  mylcd.Set_Text_Back_colour(COL_BG);
  mylcd.Print_String(buf, x, y);

  mylcd.Set_Text_Size(1);
  mylcd.Print_String(unit, x + (intDigits + decDigits + 1) * 18 + 4, y + 16);
}

void drawDigitCursor(int x, int y, int digit, int &lastDigit, const uint8_t* charPosTable) {
  if (digit == lastDigit) return;
  int charX = x + charPosTable[digit] * 18;

  mylcd.Set_Draw_color(COL_BG);
  mylcd.Fill_Rectangle(x, y + 26, x + 108, y + 28);       // clear old cursor strip

  mylcd.Set_Draw_color(COL_CURSOR);
  mylcd.Fill_Rectangle(charX, y + 26, charX + 17, y + 28); // draw new cursor mark

  lastDigit = digit;
}

void drawCCFlag() {
  if (ccActive == lastDrawnCC) return;
  lastDrawnCC = ccActive;

  mylcd.Set_Draw_color(COL_BG);
  mylcd.Fill_Rectangle(120, 200, 200, 230);

  mylcd.Set_Text_Size(2);
  mylcd.Set_Text_Back_colour(COL_BG);
  if (ccActive) {
    mylcd.Set_Text_colour(COL_CC);
    mylcd.Print_String("CC", 125, 208);
  } else {
    mylcd.Set_Text_colour(COL_CV);
    mylcd.Print_String("CV", 125, 208);
  }
}

void updateDisplay() {
  drawField(10, 65, setVoltage, lastDrawnSetV, COL_SETV, 2, 3, "V");
  drawDigitCursor(10, 65, vDigit, lastDrawnVDigit, vDigitCharPos);

  drawField(10, 120, measuredVoltage, lastDrawnMeasV, COL_OUTV, 2, 3, "V");

  drawField(170, 65, setCurrentLimit, lastDrawnSetI, COL_SETV, 1, 3, "A");
  drawDigitCursor(170, 65, iDigit, lastDrawnIDigit, iDigitCharPos);

  drawField(170, 120, measuredCurrent, lastDrawnMeasI, COL_OUTV, 1, 3, "A");

  drawCCFlag();
}

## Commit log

2026-03-15 Initial commit: Digitally Controlled Mixed-Signal Power Supply
    [Adj_power.kicad_pcb, Adj_power.kicad_sch]
2026-03-15 Update output current specification to 1.0 A
2026-03-15 Update microcontroller reference to Arduino Nano (ATmega328P)
